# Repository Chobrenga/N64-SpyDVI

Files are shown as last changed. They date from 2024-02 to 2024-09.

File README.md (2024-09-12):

# Meet the N64 SpyDVI

N64 DVI mod board using RP2040 and some DVI bit banging firmware from the [PicoDVI-N64](https://github.com/kbeckmann/PicoDVI-N64) project. Should be able to be installed as cut or no cut.

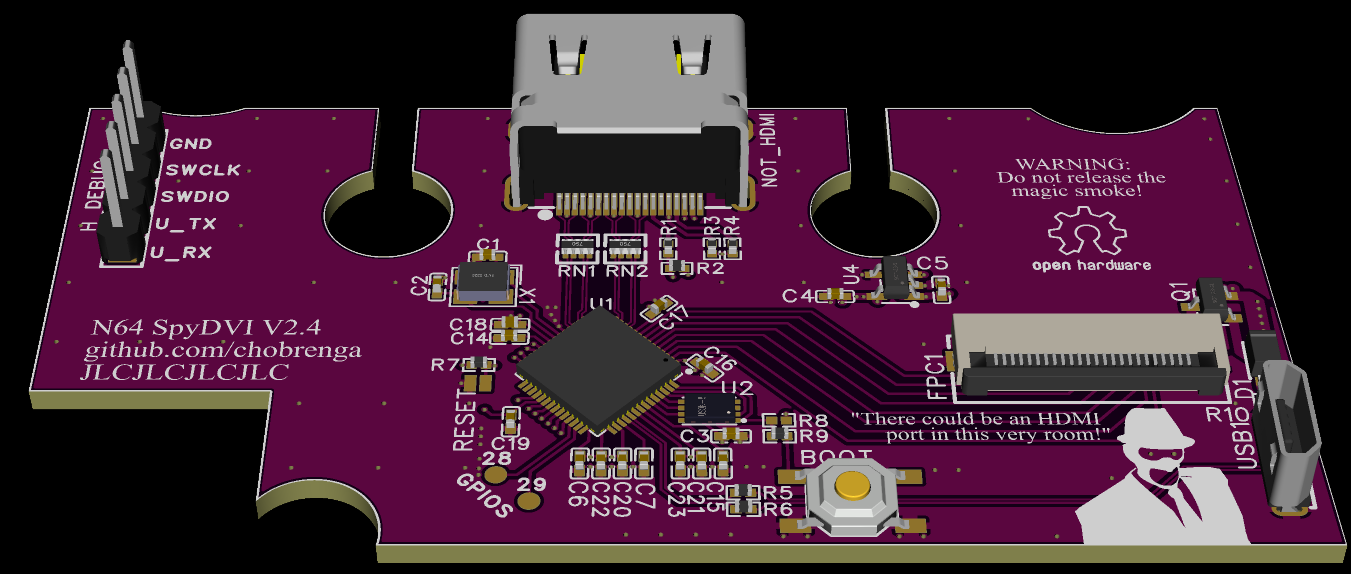
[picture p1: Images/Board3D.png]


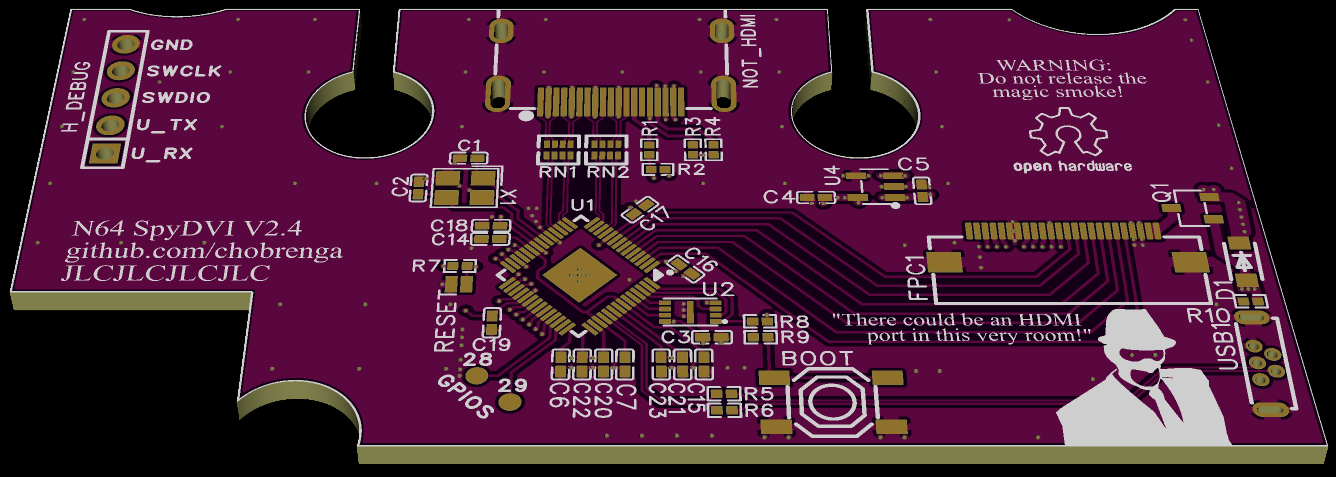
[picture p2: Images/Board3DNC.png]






~~Currently no QSB, use N64 Header. N64 Header is a 20 pin 1.27mm pitch connection, of which can be bought on Amazon.~~

Please use the QSB moving forward. The header had too many signaling issues. My first batch of the QSB is being ordered soon for testing. :)

The board only needs a 5V supply, there is a 3.3V regulator onboard to generate logic level. The RP2040 itself generates the 1.1V it needs for operaton. The MOSFET Q1 cuts off the 5V from the console when the usb is inserted, so it should be able to be programmed while installed.

Custom 3D printed bracket, braces, and facia are planned, but not yet available. The ones from Peter Bartmann's [n64adv2_pcb](https://github.com/borti4938/n64adv2_pcb) should work just fine.

# State of the Project

After receiving the flex cable and seeing the system working with audio finally, I began working on the software side of things. It very quickly became apparent to me that the 2040 is not a great choice for this kind of application, as the image distorts whenever I attempt to read controller inputs. This appears to be a performance issue. There may not be another update after this one.

# Fabrication Notes

~~This board has not been fabricated and tested as of yet. I have placed an order and will be testing very soon. If you do order, I always recommended the latest revision.~~

The board worked well enough that I will continue the project. With no audio lines connected, I got a clean video signal. Currently working on the QSB.

**R8** is intentionally missing on the BOM. It is not required. May be removed from schematic in final design.
**RESET** is missing in the BOM, this is because it's only a pair of pads. This is not an issue.

This is intended for fabrication with **JLC04161H-7628(Standard)**. Enable **impedance control**.

### Potential cost savings

Leaving the debug header unpopulated would save some cost for the final production run.

~~Removing the N64 pin header and stuffing resistors would reduce cost, once the QSB is available.~~

Potential to shrink the board layout and panelize the board, could significantly reduce manufacturing costs.

### Revision Notes

#### Main Board
* For V2.0 Select 0.15mm via option, 4-Wire Kelvin Test is mandatory. (Not recommended, use newer revision)
* For V2.1 Select 0.25mm via option, 4-Wire Kelvin Test is still mandatory.
* For V2.2 and beyond vias are 0.3mm minimum, so no special requirements regarding testing. This was done to reduce manufacturing costs.
* For V2.3 things were only slightly moved around. Was not worth going to the trouble to update the GitHub.
* For V2.4 the N64 Pin Header was removed along witht he stuffing resistors. Header was causing signal reflection issues.

#### Ribbon
* V1.0C is a compatibility version for main boards V2.0 and V2.1
* V1.0 is for V2.2 and newer. It has a few errors.
* V1.1 removes solder mask from the FPC connection area, along with fixing a few small issues.

This is not and will not be compatible with the Hispeedido flex cable, even though they have the same number of pins.

# Credit Given

Konrad Beckmann for initial inspiration and some initial firmware. Repo: [PicoDVI-N64](https://github.com/kbeckmann/PicoDVI-N64)

Wren6991 for sparking Konrad's project, and providing a functional DVI board schematic which my design is based on. [PicoDVI](https://github.com/Wren6991/PicoDVI)

The various and wonderful people in Konrad Beckmann's Discord server have also been a massive help! Thank you all!

# Schematics

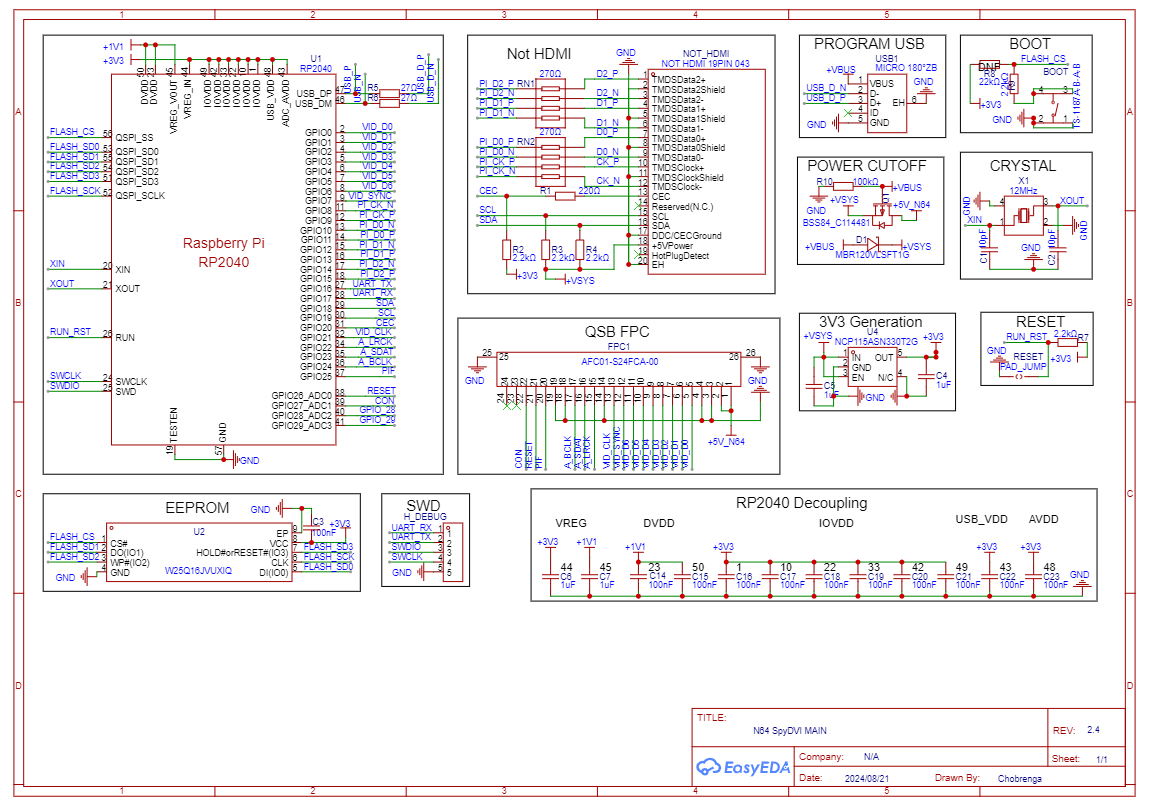
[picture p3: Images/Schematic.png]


## QSB Ribbon

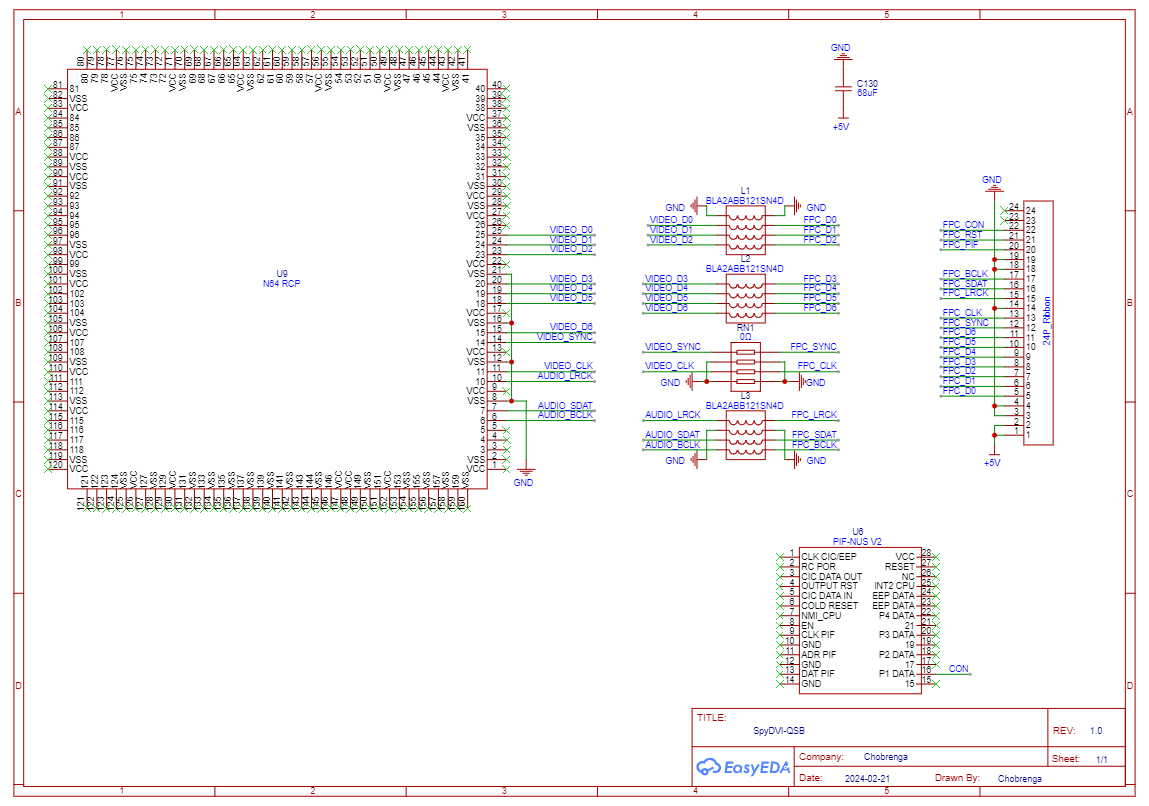
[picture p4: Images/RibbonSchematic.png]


# Wiring

Note: Controller support currently not implemented.
Note: The QSB handles all AV Signals. Power, GND, and CON still need wires.

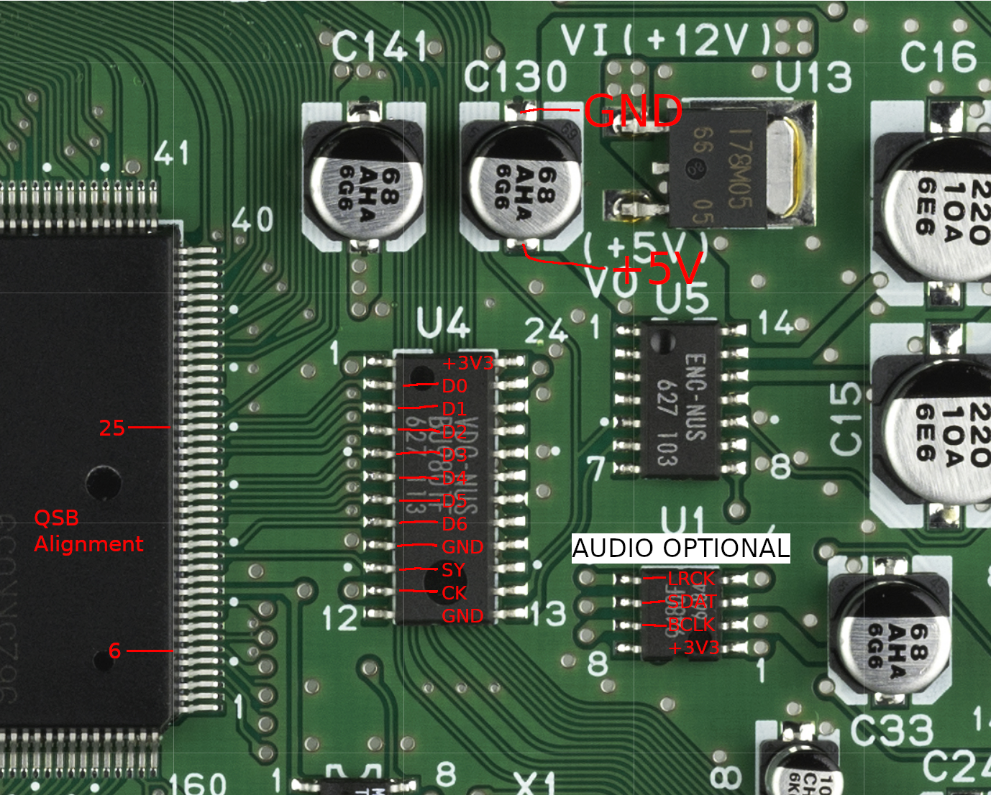
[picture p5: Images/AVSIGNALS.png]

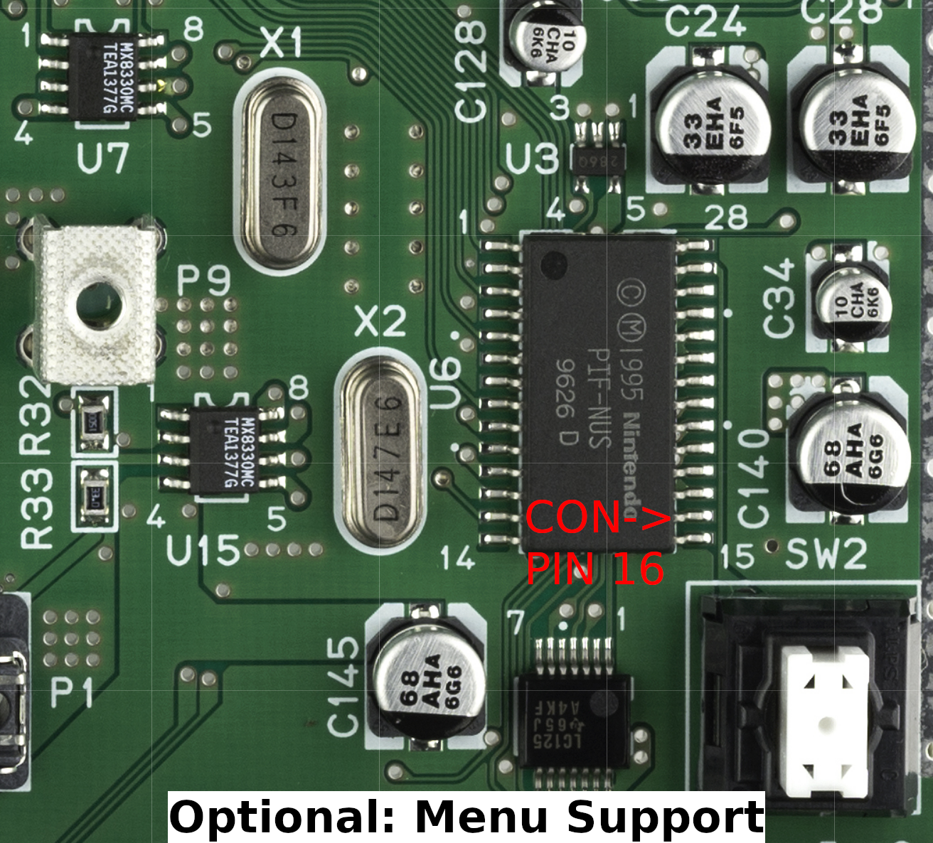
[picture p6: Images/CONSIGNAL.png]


Below is an example of an installed kit.

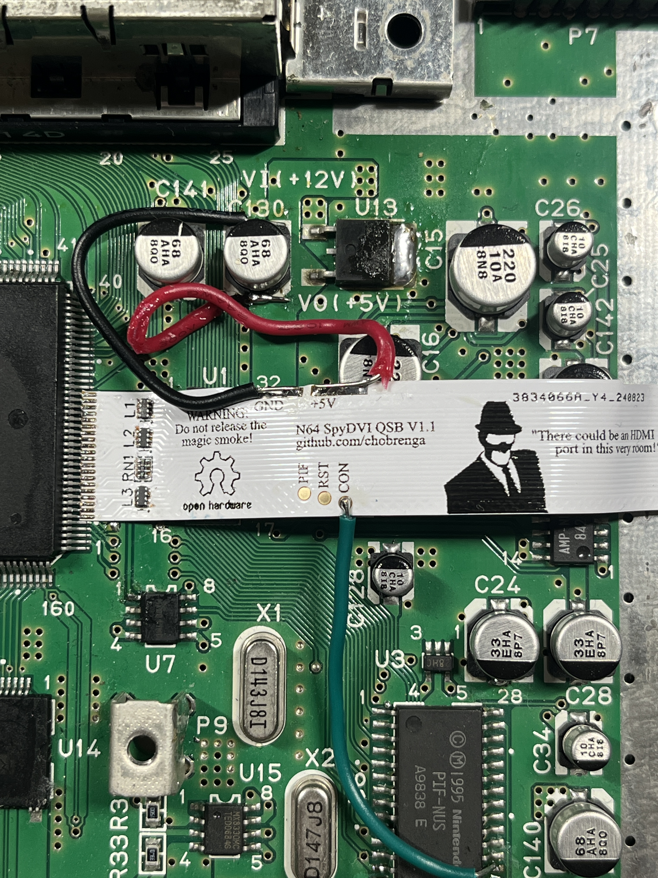
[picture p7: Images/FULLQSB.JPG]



# Board Layout

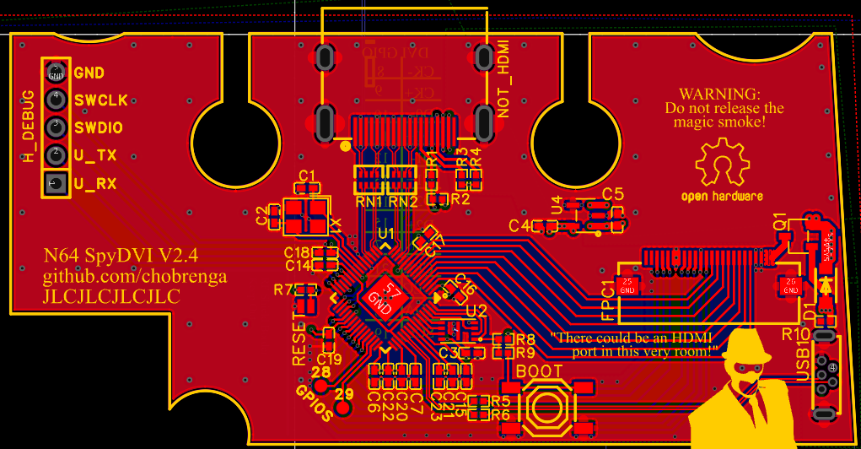
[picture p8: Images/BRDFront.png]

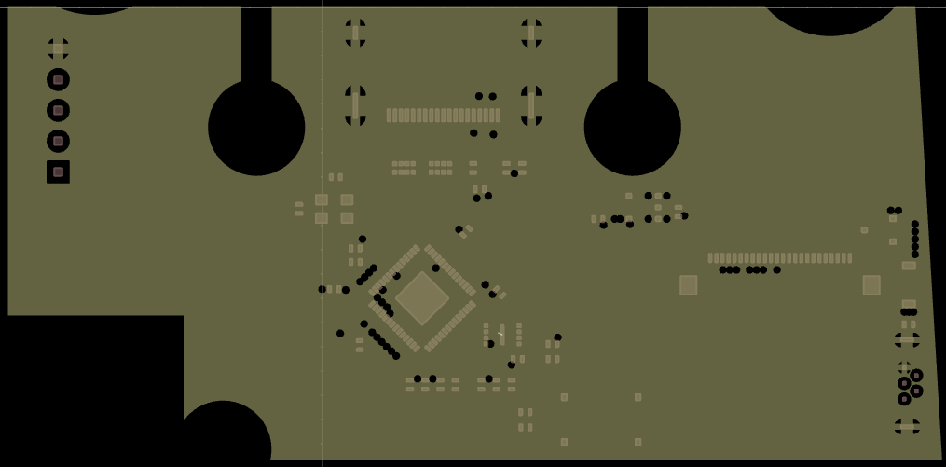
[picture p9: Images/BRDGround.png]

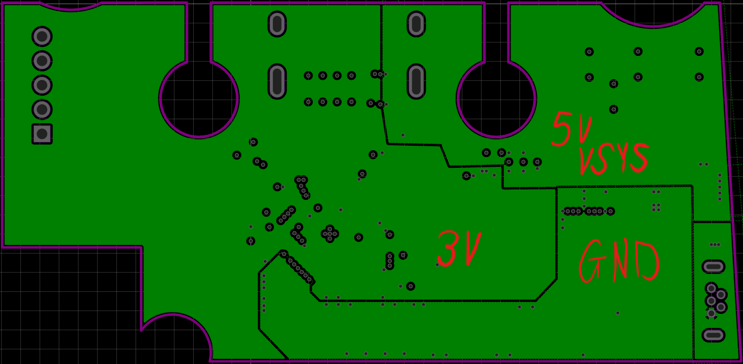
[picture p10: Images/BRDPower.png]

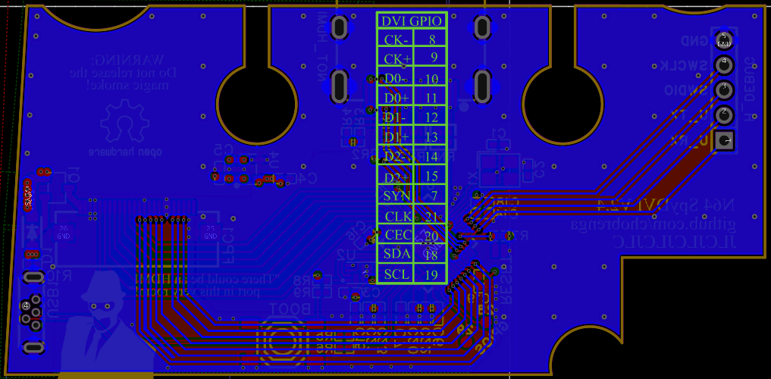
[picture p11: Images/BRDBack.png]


## Ribbon layout

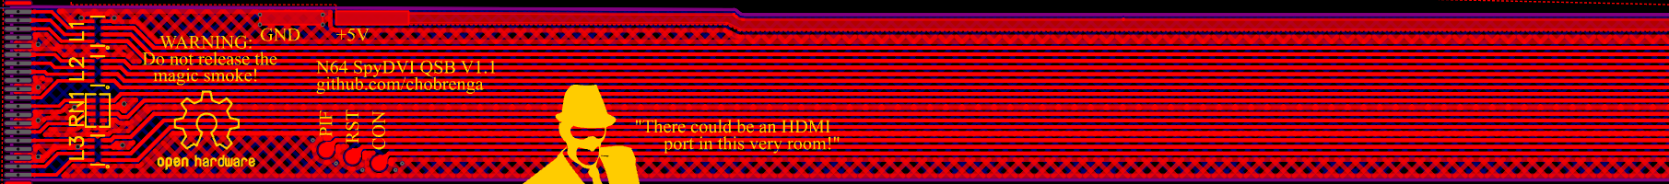
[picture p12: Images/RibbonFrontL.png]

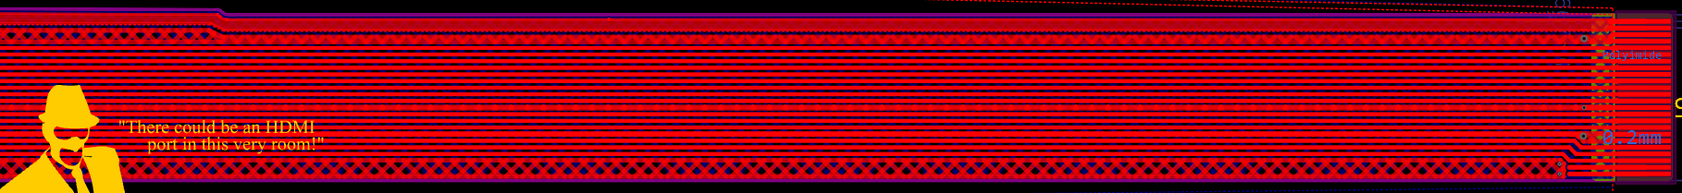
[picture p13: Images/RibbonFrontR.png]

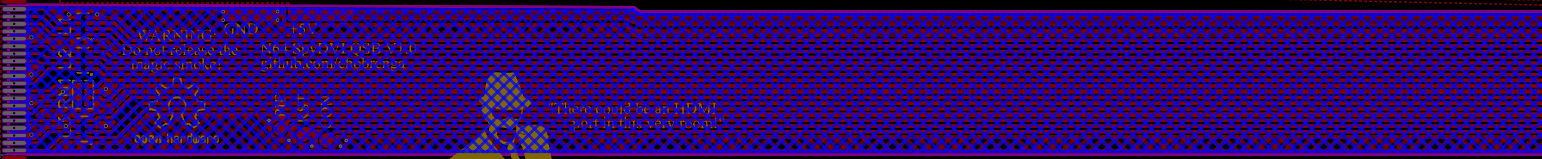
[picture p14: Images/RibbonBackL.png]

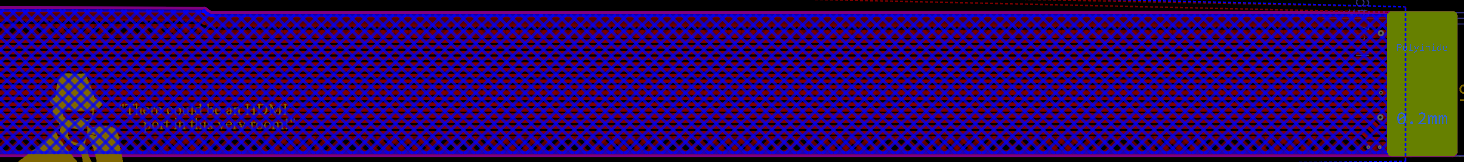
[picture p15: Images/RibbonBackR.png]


# Fitment

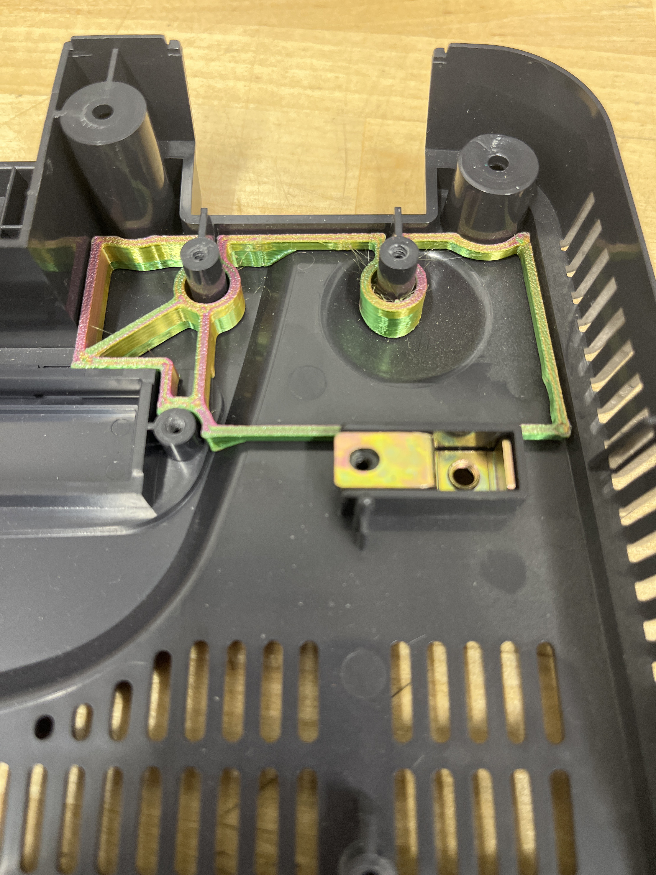
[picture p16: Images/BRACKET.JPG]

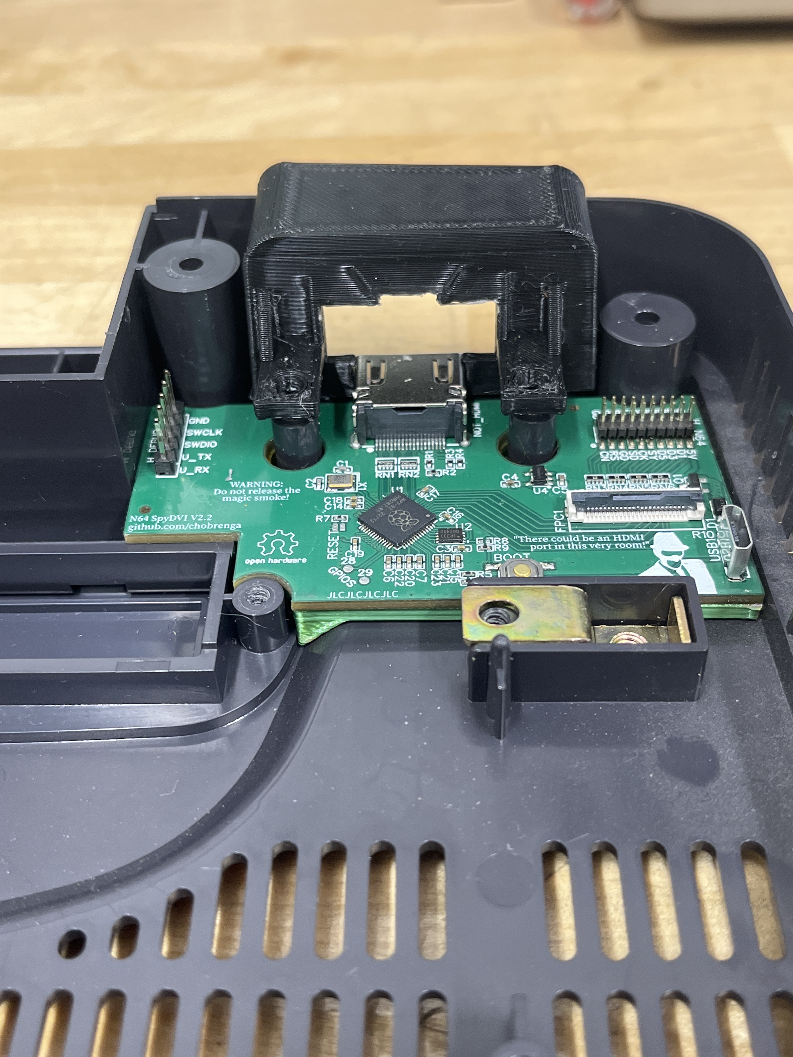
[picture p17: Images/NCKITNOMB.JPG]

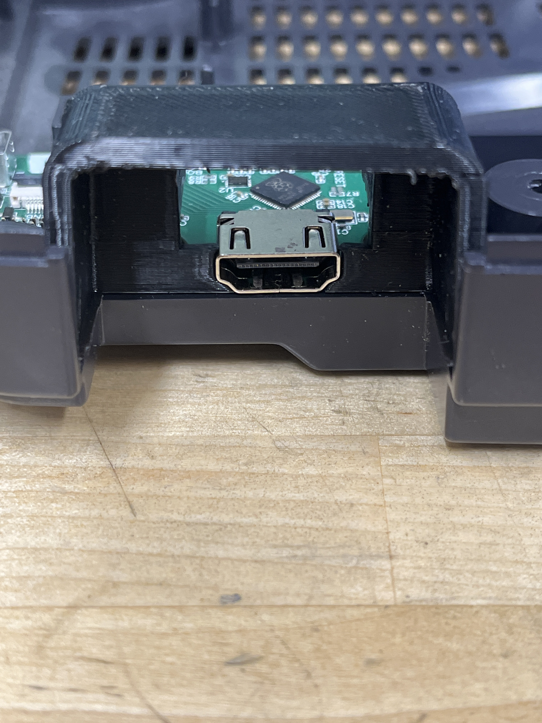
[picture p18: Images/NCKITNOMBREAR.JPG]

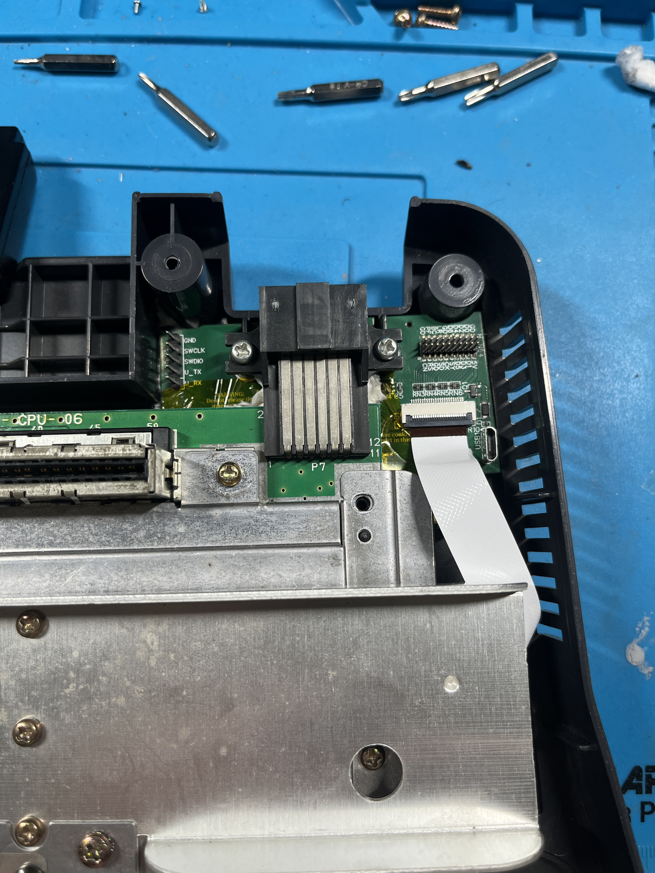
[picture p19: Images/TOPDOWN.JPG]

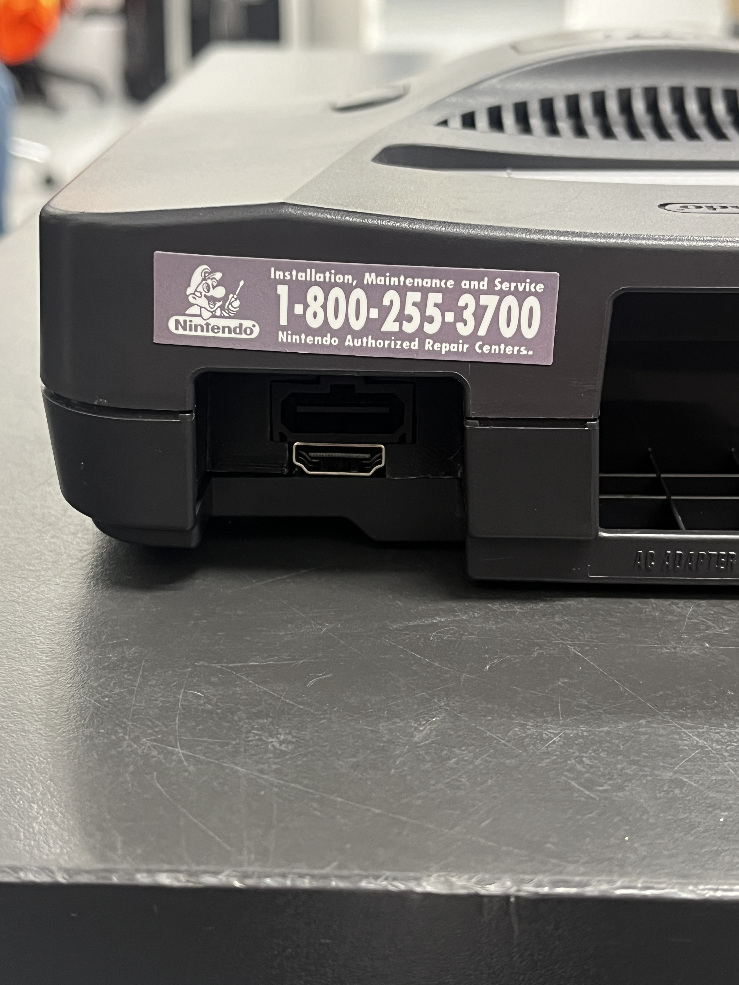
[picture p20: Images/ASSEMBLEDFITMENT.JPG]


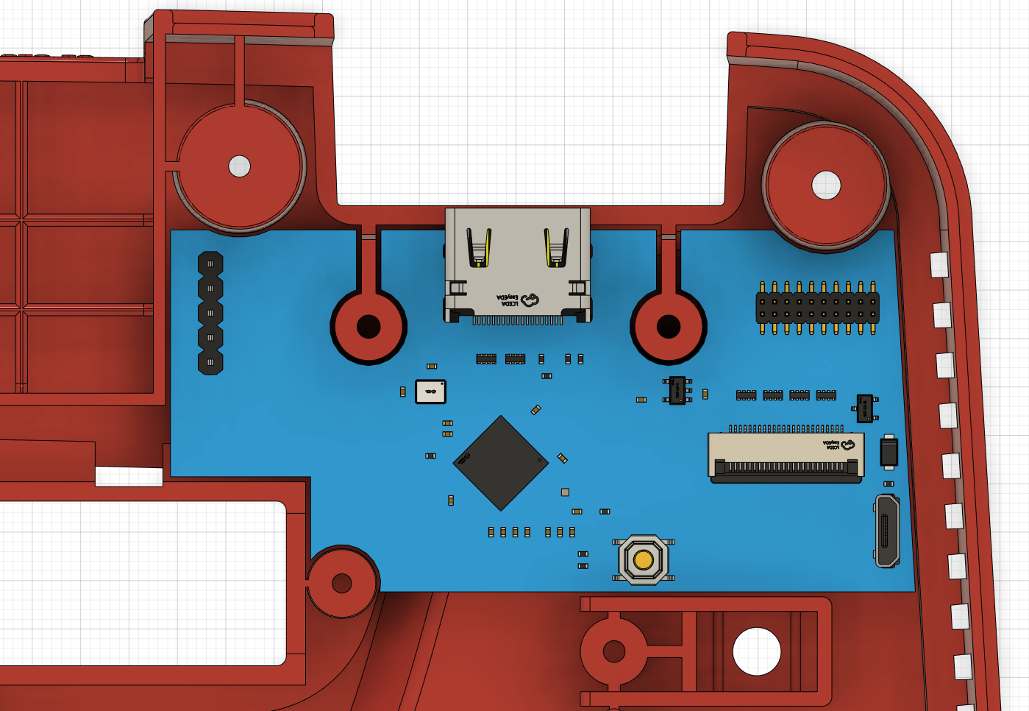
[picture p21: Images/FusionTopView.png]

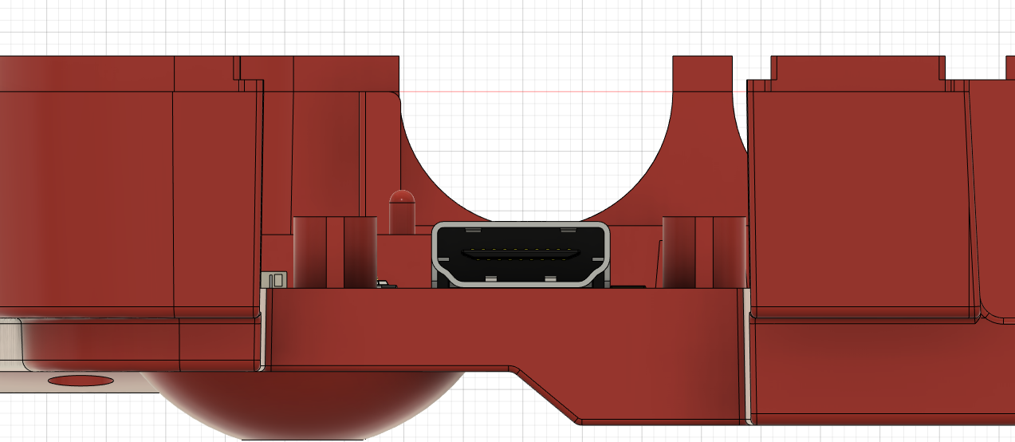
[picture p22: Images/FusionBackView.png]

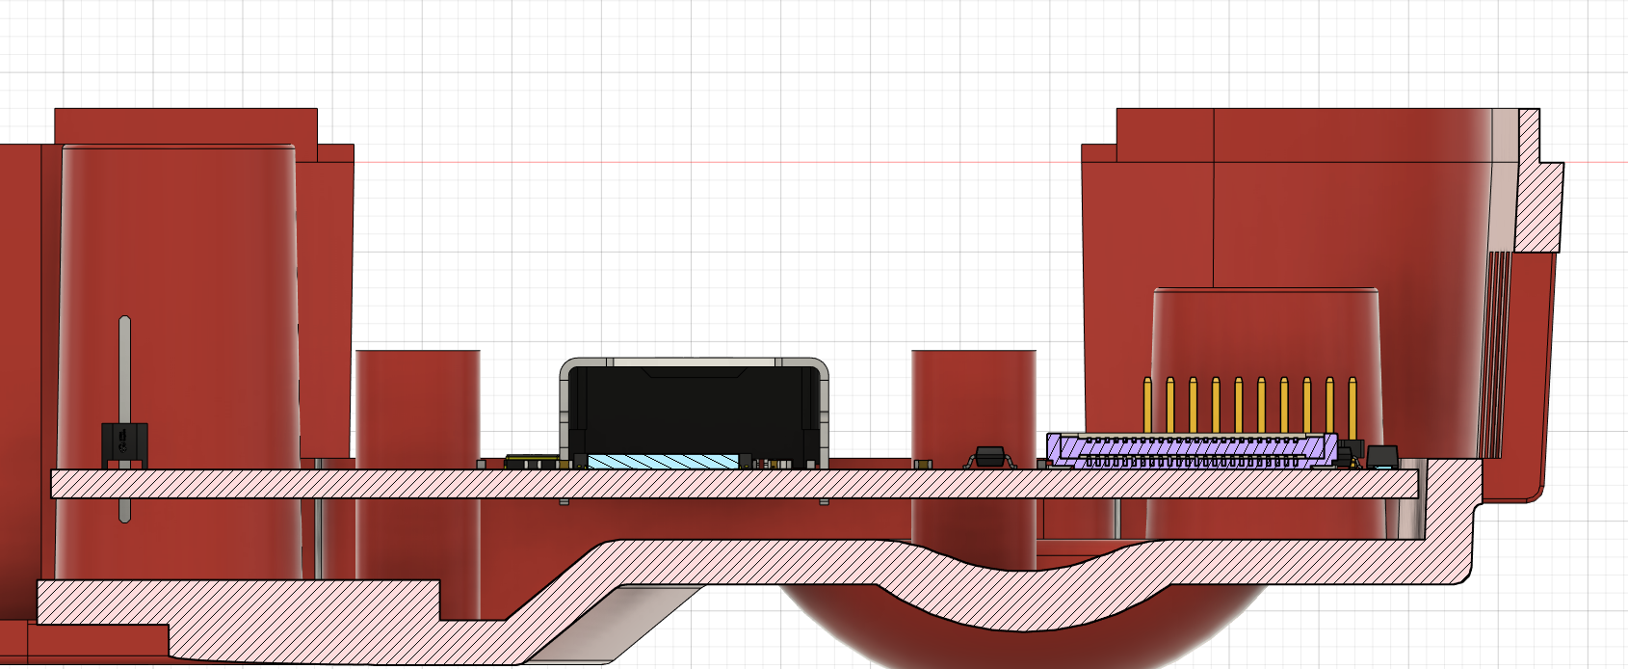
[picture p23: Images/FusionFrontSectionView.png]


# Software Notes

The project started with EasyEDA Standard edition, but has migrated to EasyEDA Pro for the Flex Cable support.

# Development Tasks
- [X] Layout Board
- [X] Order first production run
- [X] Modify Konrad's Firmware for SpyDVI
- [X] Test first production run
- [X] Add control monitoring
- [X] Design QSB Ribbon V1
- [X] Order QSB Ribbon V1
- [X] Take pictures of QSB install for Readme
- [X] ~Test QSB with an without V2.2 stuffing resistors~ No need, works with them.
- [X] Design Compatibility version of QSB Ribbon for older boards
- [X] Design 3D Printed No-Cut Kit
- [ ] Convert project to RP2350
- [ ] Find appropriate scaling methods
- [ ] Side-By-Side Test VS Multi Out
- [ ] Add settings menu and Hotkeys
- [ ] Design and order QSB with no components to see if they are necesarry.
- [ ] Design 3D Printed Cut Kit

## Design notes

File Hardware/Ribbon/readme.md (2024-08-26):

# Revisions
* V1.0C is a compatibility version for main boards V2.0 and V2.1
* V1.0 is for V2.2 and newer. It has a few errors.
* V1.1 removes solder mask from the FPC connection area, along with fixing a few small issues.

# Component Specs
* 3x 600mΩ ±25% 120Ω@100MHz Ferrite Beads (4 circuits)
* 1x 0Ω Resistor Array (4 circuits)

# BOM
* 3x BLA2ABB121SN4D L1, L2, L3
* 1x RC-MT08W000JT RN1

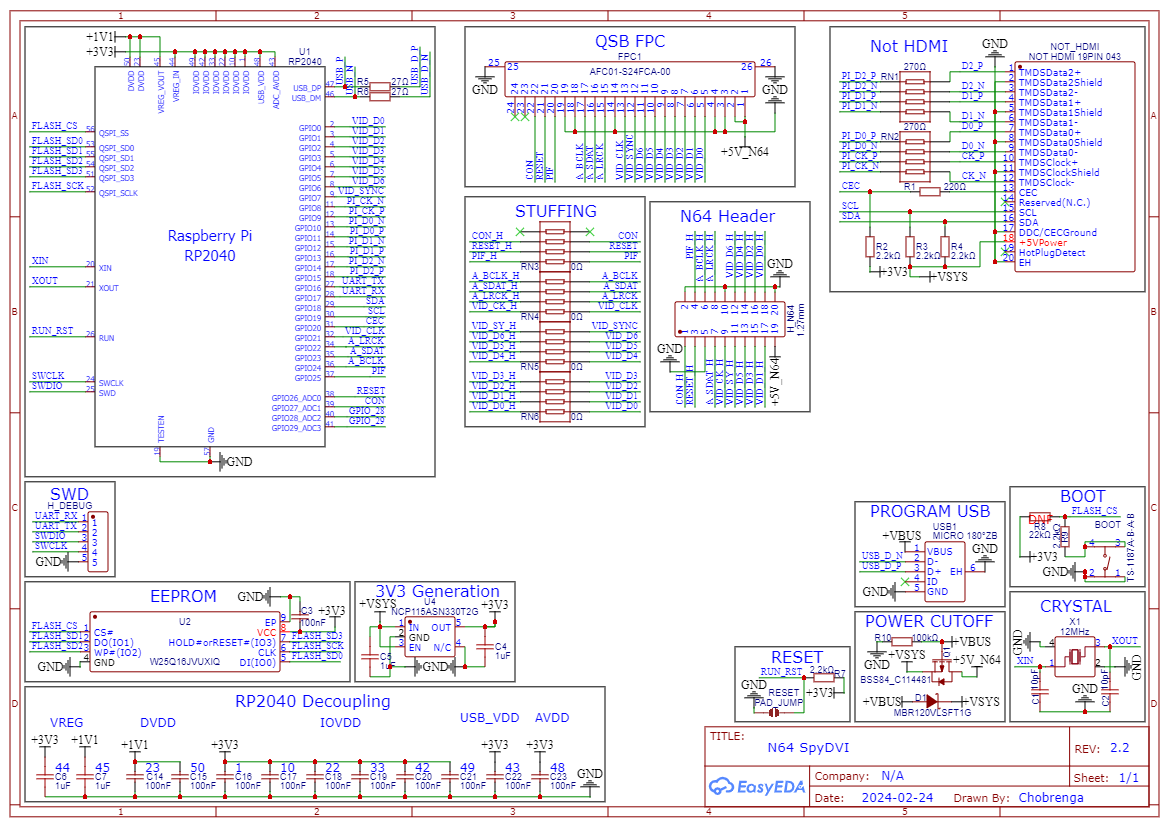
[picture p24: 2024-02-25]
Images/V2_2/Schematic.png

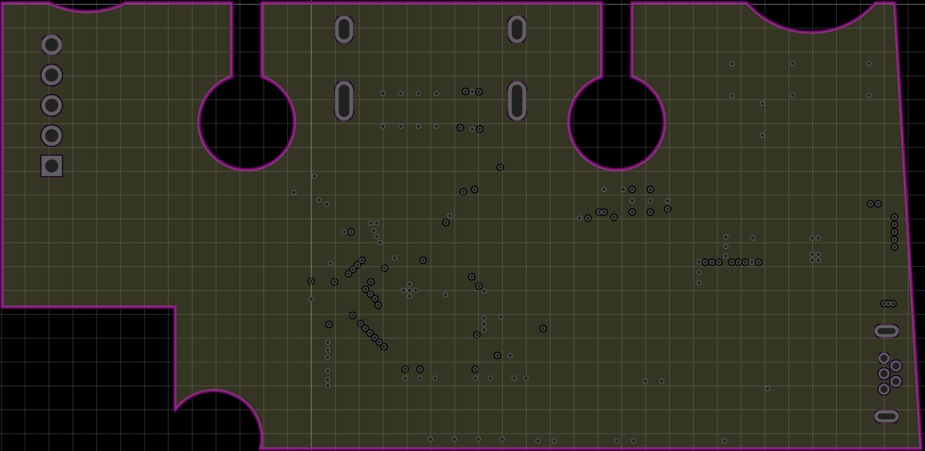
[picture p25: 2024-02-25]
Images/V2_2/BRDGround.png

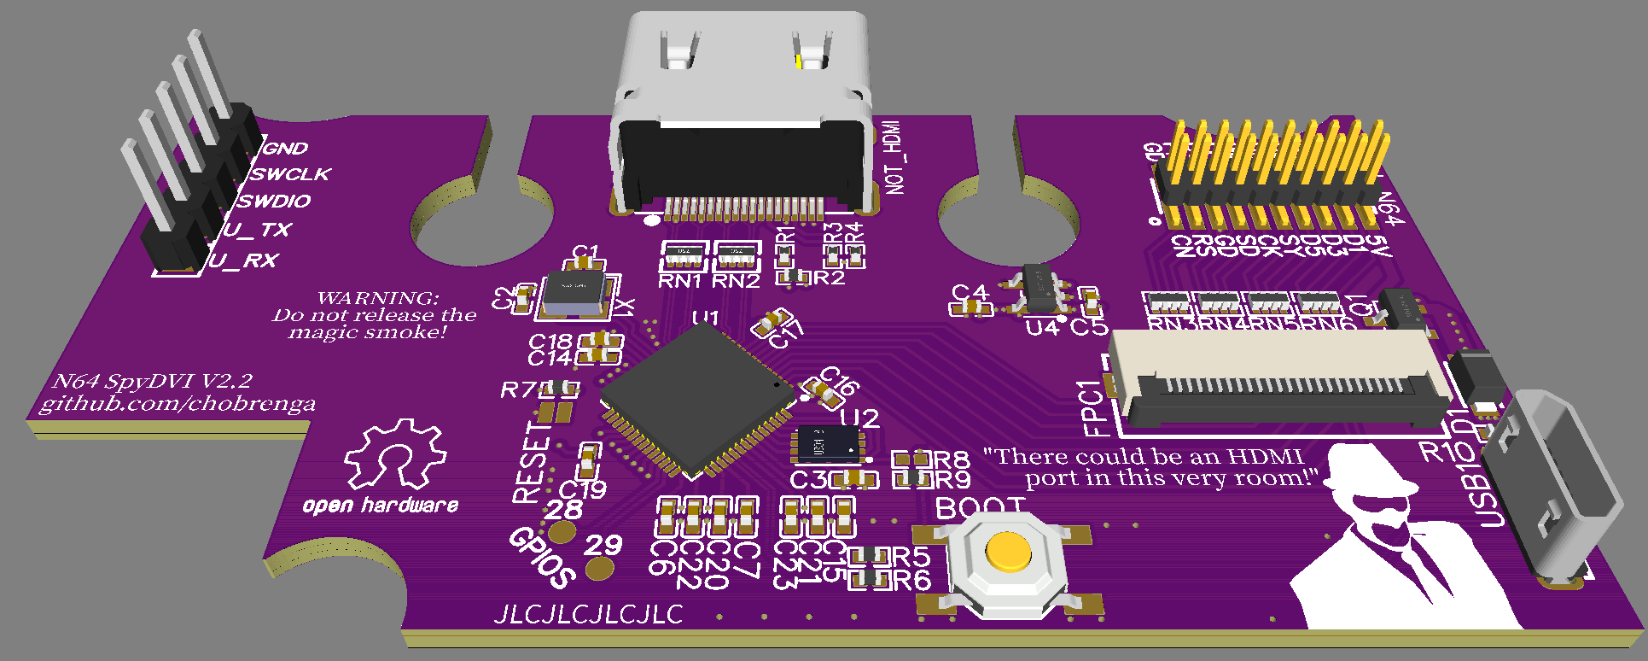
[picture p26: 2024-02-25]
Images/V2_2/Board3D.png

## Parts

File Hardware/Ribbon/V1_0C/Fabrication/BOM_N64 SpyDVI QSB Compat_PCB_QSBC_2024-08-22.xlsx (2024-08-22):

No. | Quantity | Comment | Designator | Footprint | Value | Manufacturer Part | Manufacturer | Supplier Part | Supplier
1 | 3 | BLA2ABB121SN4D | L1,L2,L3 | BEAD-SMD_8P-L2.0-W1.0-P0.50-TL |  | BLA2ABB121SN4D | muRata(村田) | C440126 | LCSC
2 | 1 | 0Ω | RN1 | RES-ARRAY-SMD_0402-8P-L2.0-W1.0-BL |  | RC-MT08W000JT | FH(风华) | C2001 | LCSC

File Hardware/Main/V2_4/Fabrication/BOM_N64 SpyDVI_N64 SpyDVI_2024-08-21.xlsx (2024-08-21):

No. | Quantity | Comment | Designator | Footprint | Value | Manufacturer Part | Manufacturer | Supplier Part | Supplier
1 | 1 | TS-1187A-B-A-B | BOOT | SW-SMD_4P-L5.1-W5.1-P3.70-LS6.5-TL-2 |  | TS-1187A-B-A-B | XKB Connectivity(中国星坤) | C318884 | LCSC
2 | 2 | 10pF | C1,C2 | C0402 |  | CL05C100JB5NNNC | SAMSUNG(三星) | C32949 | LCSC
3 | 11 | 100nF | C3,C14,C15,C16,C17,C18,C19,C20,C21,C22,C23 | C0402 |  | CL05B104KO5NNNC | SAMSUNG(三星) | C1525 | LCSC
4 | 4 | 1uF | C4,C5,C6,C7 | C0402 |  | CL05A105KA5NQNC | SAMSUNG(三星) | C52923 | LCSC
5 | 1 | MBR120VLSFT1G | D1 | SOD-123F_L2.8-W1.8-LS3.7-RD |  | MBR120VLSFT1G | onsemi(安森美) | C223608 | LCSC
6 | 1 | AFC01-S24FCA-00 | FPC1 | FPC-SMD_P0.50-24P_FGS-XJ-H2.0 |  | AFC01-S24FCA-00 | JS(钜硕电子) | C262669 | LCSC
7 | 1 | PZ254V-11-05P | H_DEBUG | HDR-TH_5P-P2.54-V-M |  | PZ254V-11-05P | XFCN(兴飞) | C492404 | LCSC
8 | 1 | NOT HDMI 19PIN 043 | NOT_HDMI | HDMI-SMD_HDMI-19PIN-043 |  | HDMI 19PIN 043 | SHOU HAN(首韩) | C2858275 | LCSC
9 | 1 | BSS84_C114481 | Q1 | SOT-23-3_L2.9-W1.6-P1.90-LS2.8-BR |  | BSS84 | CJ(江苏长电/长晶) | C114481 | LCSC
10 | 1 | 220Ω | R1 | R0402 |  | 0402WGF2200TCE | UNI-ROYAL(厚声) | C25091 | LCSC
11 | 5 | 2.2kΩ | R2,R3,R4,R7,R9 | R0402 |  | 0402WGF2201TCE | UNI-ROYAL(厚声) | C25879 | LCSC
12 | 2 | 27Ω | R5,R6 | R0402 |  | 0402WGF270JTCE | UNI-ROYAL(厚声) | C25100 | LCSC
13 | 1 | 22kΩ | R8 | R0402
14 | 1 | 100kΩ | R10 | R0402 |  | 0402WGF1003TCE | UNI-ROYAL(厚声) | C25741 | LCSC
15 | 1 | PAD_JUMP | RESET | PAD-JUMPER-2-NO_NO_SILK
16 | 2 | 270Ω | RN1,RN2 | RES-ARRAY-SMD_0804-8P-L2.0-W1.0-BL |  | CAT10-271J4LF | BOURNS | C148510 | LCSC
17 | 1 | RP2040 | U1 | LQFN-56_L7.0-W7.0-P0.4-EP |  | RP2040 | Raspberry Pi(树莓派) | C2040 | LCSC
18 | 1 | W25Q16JVUXIQ | U2 | USON-8_L3.0-W2.0-P0.50-BL-EP |  | W25Q16JVUXIQ | WINBOND(华邦) | C2843335 | LCSC
19 | 1 | NCP115ASN330T2G | U4 | SOT-23-5_L3.0-W1.7-P0.95-LS2.8-BL |  | NCP115ASN330T2G | onsemi(安森美) | C603505 | LCSC
20 | 1 | MICRO 180°ZB | USB1 | MICRO-USB-TH_MICRO-180-ZB |  | MICRO 180°ZB | SHOU HAN(首韩) | C668588 | LCSC
21 | 1 | 12MHz | X1 | CRYSTAL-SMD_4P-L3.2-W2.5-BL |  | X322512MMB4SI | YXC(扬兴晶振) | C50430 | LCSC

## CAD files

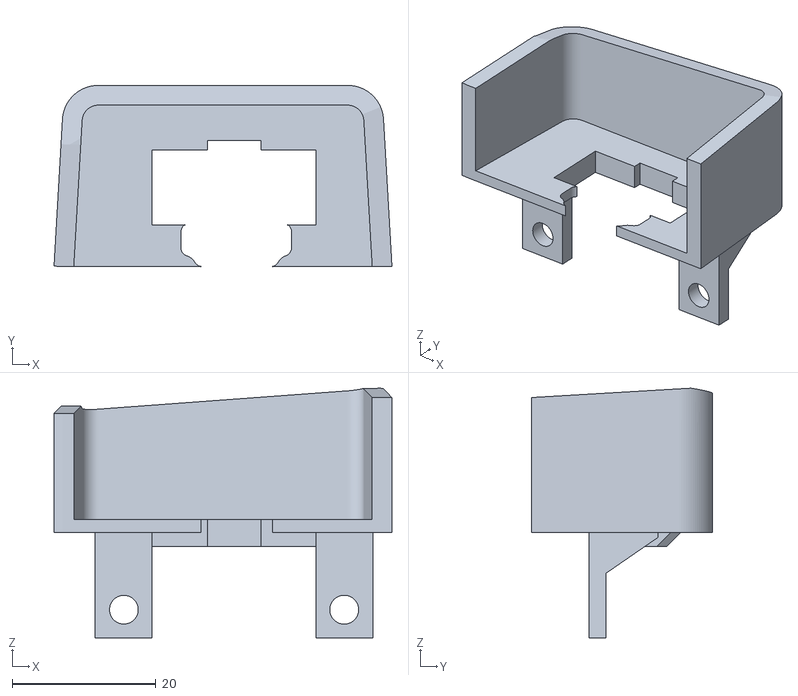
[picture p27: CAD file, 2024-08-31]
3D Files/N64Adv2_MultiOut_NoCut.stl
47.1 x 25.3 x 34.8

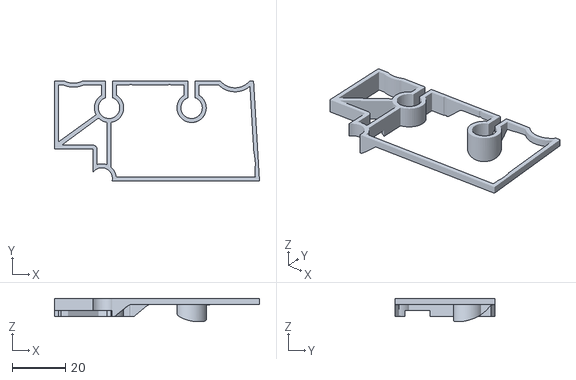
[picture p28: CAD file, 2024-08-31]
3D Files/N64 Bracket.stl
77.0 x 37.4 x 8.79

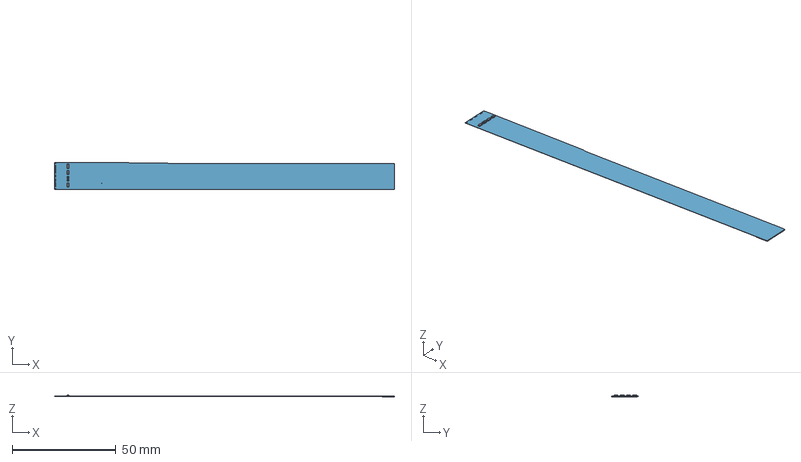
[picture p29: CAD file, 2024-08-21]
3D Files/N64 SpyDVI QSB_1_0.step
163.9 x 13.1 x 0.753 mm
Board

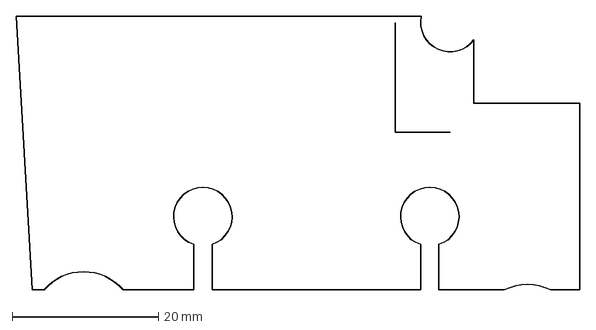
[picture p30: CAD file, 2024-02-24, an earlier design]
Hardware/Main/V2_0/SpyDVIBoardOutline.dxf
77.0 x 37.4 mm

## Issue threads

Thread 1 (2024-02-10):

R8 missing in BOM

bbsan2k, 2024-02-10:
Hi,
Thanks for this great project!
Is it possible, that R8 is missing in the BOM file?

Chobrenga, 2024-02-11:
That was intentional. It is there so there are pads to add a 22k pull-up if there are issues with the FLASH_CS/BOOT signal. The RP2040 has an internal 60k 20% pull-up on that line.

If you're planning to produce the board as it sits, I must warn you I've been made aware of several design oversights and it may not work at all. I'm fed up with EasyEDA crashing also, and am currently porting the project to Kicad.

bbsan2k, 2024-02-11:
Thanks for your reply! That’s really good to know - I guess I’ll wait for the new version then😉
I was looking for exactly this kind of board😊

Closed 2024-02-11.

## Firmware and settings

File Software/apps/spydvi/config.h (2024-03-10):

/**
 * SPDX-License-Identifier: BSD-3-Clause
 *
 * Copyright (c) 2023 Konrad Beckmann
 */

/**
 * @file config.h
 * @brief Configuration management functions and global configuration variable.
 */

#pragma once

#include <stdint.h>

/// Default crop X parameter for PAL.
#define DEFAULT_CROP_X_PAL  (36)

/// Default crop X parameter for NTSC.
#define DEFAULT_CROP_X_NTSC (14)

/// Default crop Y parameter for PAL.
#define DEFAULT_CROP_Y_PAL  (90)

/// Default crop Y parameter for NTSC.
#define DEFAULT_CROP_Y_NTSC (25)

/// Number of rows for PAL.
#define ROWS_PAL            (615)

/// Number of rows for NTSC.
#define ROWS_NTSC           (511)

/// Tolerance for number of rows.
#define ROWS_TOLERANCE      (5)

/// Y offset for OSD.
#define OSD_Y_OFFSET (3)

/// X offset for OSD.
#define OSD_X_OFFSET (5)

/// TMDS bit clock 252 MHz
/// DVDD 1.2V (1.1V seems ok too)
/// Voltage regulator selection.
#define VREG_VSEL VREG_VOLTAGE_1_20

/// DVI timing configuration.
#define DVI_TIMING dvi_timing_640x480p_60hz

/// UART config on the last GPIOs
/// UART transmission pin.
#define UART_TX_PIN (16)

/// UART reception pin (not available on the pico).
#define UART_RX_PIN (17)

/// UART identifier.
#define UART_ID     uart0

/// Baud rate for UART communication.
#define BAUD_RATE   115200

/**
 * @brief The number of bits to shift to get the audio buffer size.
 *
 * This value is used to calculate the size of the audio buffer by shifting
 * 1 to the left by this number of bits. For example, if
 * AUDIO_BUFFER_SIZE_BITS is 12, then the audio buffer size will be
 * 1 << 12, or 4096.
 */
#define AUDIO_BUFFER_SIZE_BITS 12

/**
 * @brief The size of the audio buffer.
 *
 * This is calculated as 1 << AUDIO_BUFFER_SIZE_BITS. So if
 * AUDIO_BUFFER_SIZE_BITS is 12, then AUDIO_BUFFER_SIZE will be 4096.
 */
#define AUDIO_BUFFER_SIZE (1 << AUDIO_BUFFER_SIZE_BITS)

/**
 * @def USE_RGB555
 * @brief A macro to control the color depth of the display.
 *
 * When defined, the display will use RGB555 color depth, which provides
 * 5 bits for each of the red, green, and blue color channels. This results
 * in a total of 32,768 possible colors.
 *
 * RGB555 can sometimes look better than RGB565 because it provides a balanced
 * color depth across all three color channels. This can result in more accurate
 * color reproduction, especially for images that have a balanced mix of colors.
 * However, it does provide fewer total colors than RGB565.
 *
 * If this macro is not defined, and USE_RGB565 is defined instead, the display
 * will use RGB565 color depth. This provides 5 bits for red, 6 bits for green,
 * and 5 bits for blue, resulting in a total of 65,536 possible colors. The
 * extra bit for the green channel is because the human eye is more sensitive
 * to variations in green than in red or blue.
 */
#define USE_RGB555
// #define USE_RGB565

/**
 * @def AUDIO_ENABLED
 * @brief A macro to control the audio input functionality.
 *
 * When set to 1, the audio input functionality is enabled. This means that the
 * application will process and output audio data. However, this will only work
 * if the necessary audio input wires have been correctly soldered to the
 * appropriate pins on the hardware.
 *
 * When set to 0, the audio input functionality is disabled. This can be useful
 * for debugging, or when running on hardware where the audio input wires have
 * not been soldered.
 */
#define AUDIO_ENABLED 1
// #define AUDIO_ENABLED 0

/**
 * @def DIAGNOSTICS
 * @brief A macro to control the display of diagnostic data.
 *
 * When defined, the application will print diagnostic data on the screen.
 * This can be useful for debugging and performance tuning.
 *
 * When not defined, no diagnostic data will be displayed.
 */
// #define DIAGNOSTICS

/**
 * @def DIAGNOSTICS_JOYBUS
 * @brief A macro to control the display of Joybus diagnostic data.
 *
 * When defined, the application will print Joybus-specific diagnostic data
 * on the screen. This can be useful for debugging and performance tuning
 * of the Joybus communication.
 *
 * When not defined, no Joybus diagnostic data will be displayed.
 */
// #define DIAGNOSTICS_JOYBUS

/**
 * @def CONFIG_MAGIC1
 * @brief A magic number used for configuration validation.
 *
 * This magic number is used as part of a mechanism to validate the
 * configuration data. It should be stored in a known location in the
 * configuration data, and checked when the configuration data is read.
 * If it does not match the expected value, this indicates that the
 * configuration data is not valid, and default values should be used instead.
 */
#define CONFIG_MAGIC1 0x12345678

/**
 * @def CONFIG_MAGIC2
 * @brief A second magic number used for configuration validation.
 *
 * This magic number is used as part of a mechanism to validate the
 * configuration data, in conjunction with CONFIG_MAGIC1. It provides an
 * additional check to ensure the integrity of the configuration data.
 */
#define CONFIG_MAGIC2 0xdeadf00d

/**
 * @enum dvi_color_mode
 * @brief Enumerates the supported color modes.
 */
typedef enum dvi_color_mode {
    DVI_RGB_555 = 0, ///< 15-bit color mode (5 bits each for red, green, and blue).
    DVI_RGB_565,     ///< 16-bit color mode (5 bits for red and blue, 6 bits for green).
    DVI_RGB_888,     ///< 24-bit color mode (8 bits each for red, green, and blue).
} dvi_color_mode_t;

/**
 * @enum sample_rate_hz
 * @brief Enumerates the supported output audio sample rates in Hertz.
 */
typedef enum sample_rate_hz {
    SAMPLE_RATE_32000_HZ = 32000, ///< 32,000 Hz sample rate.
    SAMPLE_RATE_44100_HZ = 44100, ///< 44,100 Hz sample rate.
    SAMPLE_RATE_48000_HZ = 48000, ///< 48,000 Hz sample rate.
    SAMPLE_RATE_96000_HZ = 96000, ///< 96,000 Hz sample rate.
} sample_rate_hz_t;

/**
 * @struct config
 * @brief Represents the configuration for the application.
 */
typedef struct config {
    uint32_t magic1;                ///< The first magic number used for configuration validation.
    uint32_t audio_out_sample_rate; ///< The audio output sample rate in Hertz (see @ref sample_rate_hz_t).
    uint32_t dvi_color_mode;        ///< The DVI color mode (see @ref dvi_color_mode_t).
    uint32_t magic2;                ///< The second magic number used for configuration validation.
} config_t;

/**
 * @brief Global configuration variable.
 *
 * This variable holds the current configuration for the application.
 * It can be initialized with default values using config_init(),
 * loaded from flash memory using config_load(), and saved to flash
 * memory using config_save().
 */
extern config_t g_config;

/**
 * @brief Initializes the global configuration with default values.
 *
 * This function sets the fields of g_config to their default values.
 * It should be called when the application starts, before any other
 * configuration management functions are used.
 */
void config_init(void);

/**
 * @brief Loads the configuration from flash memory into g_config.
 *
 * This function reads the configuration data from flash memory and
 * stores it in g_config. If the configuration data in flash memory
 * is not valid (as determined by the magic numbers), this function
 * will leave g_config unchanged.
 */
void config_load(void);

/**
 * @brief Saves the configuration from g_config to flash memory.
 *
 * This function writes the configuration data from g_config to flash
 * memory. This allows the current configuration to be preserved when
 * the application is restarted.
 */
void config_save(void);

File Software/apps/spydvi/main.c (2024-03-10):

/**
 * SPDX-License-Identifier: BSD-3-Clause
 *
 * Copyright (c) 2023 Konrad Beckmann
 */

// #pragma GCC optimize("Os")
// #pragma GCC optimize("O2")
#pragma GCC optimize("O3")


#include "config.h"

#include <stdio.h>
#include <stdlib.h>
#include <stdarg.h>
#include "hardware/vreg.h"
#include "pico/multicore.h"
#include "pico/stdlib.h"
#include "hardware/dma.h"
#include "hardware/uart.h"

#include "dvi.h"
#include "dvi_serialiser.h"
#include "common_dvi_pin_configs.h"
#include "sprite.h"

#include "joybus.h"

#include "joybus.pio.h"
#include "n64.pio.h" // n64.pio contains pin mapping :)

#include "gfx.h"
#include "osd.h"

// Enable to print debug/diagnostics
//#define DIAGNOSTICS
//#define DIAGNOSTICS_JOYBUS

// Crop configuration for PAL vs NTSC
#define IN_RANGE(__x, __low, __high) (((__x) >= (__low)) && ((__x) <= (__high)))
#define IN_TOLERANCE(__x, __value, __tolerance) IN_RANGE(__x, (__value - __tolerance), (__value + __tolerance))

#define ARRAY_SIZE(x) (sizeof(x)/sizeof(x[0]))

const PIO pio_joybus = DVI_DEFAULT_SERIAL_CONFIG.pio; // usually pio0
const uint sm_joybus = 3; // last free sm in pio0 unless sm_tmds is set to something unusual

const PIO pio = (DVI_DEFAULT_SERIAL_CONFIG.pio == pio0) ? pio1 : pio0;
const uint sm_video = 0;
const uint sm_audio = 1;
struct dvi_inst dvi0;

// __no_inline_not_in_flash_func
// __time_critical_func
// __not_in_flash_func

audio_sample_t      last_audio_sample;
audio_sample_t      audio_buffer[AUDIO_BUFFER_SIZE];

static void core1_main(void)
{
    dvi_register_irqs_this_core(&dvi0, DMA_IRQ_0);
    dvi_start(&dvi0);
    dvi_scanbuf_main_16bpp(&dvi0);
    __builtin_unreachable();
}

static void core1_scanline_callback(uint arg0)
{
    // Discard any scanline pointers passed back
    uint16_t *bufptr;
    while (queue_try_remove_u32(&dvi0.q_colour_free, &bufptr))
        ;
    // Note first two scanlines are pushed before DVI start
    static uint scanline = 2;
    bufptr = &g_framebuf[FRAME_WIDTH * scanline];
    queue_add_blocking_u32(&dvi0.q_colour_valid, &bufptr);
    scanline = (scanline + 1) % FRAME_HEIGHT;
}

static void set_audio_dvi_parameters(sample_rate_hz_t samplerate, bool setup)
{
	
    uint32_t cts;
    uint32_t n;

    switch (samplerate) {
    case SAMPLE_RATE_96000_HZ:
        cts = 25200;
        n = 6144 * 2;
        break;
    case SAMPLE_RATE_48000_HZ:
        cts = 25200;
        n = 6144;
        break;
    case SAMPLE_RATE_44100_HZ:
        cts = 28000;
        n = 6272;
        break;
    case SAMPLE_RATE_32000_HZ:
        cts = 25200;
        n = 4096;
        break;
    default:
        // Assume a freq. close to 32000, so let's use that
        cts = 25200;
        n = (128 * samplerate * cts) / 25200000;
        break;
    }

    if (setup) {
        dvi_set_audio_freq(&dvi0, samplerate, cts, n);
    } else {
        dvi_update_audio_freq(&dvi0, samplerate, cts, n);
    }
}

static void set_audio_sampling_parameters(sample_rate_hz_t samplerate)
{
    uint16_t numerator;
    uint16_t denominator;

    switch (samplerate) {
    case SAMPLE_RATE_96000_HZ:
        numerator = 1;
        denominator = 2625; // No error
        break;
    case SAMPLE_RATE_48000_HZ:
        numerator = 1;
        denominator = 5250; // No error
        break;
    case SAMPLE_RATE_44100_HZ:
        numerator = 4;
        denominator = 22857; // Actual freq. 44100.28 Hz
        break;
    case SAMPLE_RATE_32000_HZ:
        numerator = 1;
        denominator = 7875; // No error
        break;
    default:
        numerator = 1;
        denominator = 252000000 / samplerate; // There might be rounding errors
        break;
    }

    dma_timer_set_fraction(0, numerator, denominator);
}

void set_input_pin(int pin, bool pullup, bool pulldown)
{
	gpio_init(pin);
	gpio_set_dir(pin, GPIO_IN);

	// Enable weak internal pull downs to reduce noise when n64 is turned off
    gpio_set_pulls(pin, false, true);
}

int main(void)
{
	config_init();
    config_load();

    vreg_set_voltage(VREG_VSEL);
    sleep_ms(10);

    // Run system at TMDS bit clock (252.000 MHz)
    set_sys_clock_khz(DVI_TIMING.bit_clk_khz, true);

    // setup_default_uart();
    stdio_uart_init_full(UART_ID, BAUD_RATE, UART_TX_PIN, UART_RX_PIN);
	printf("\n");
	sleep_ms(10);
	printf("UART BEGIN\n");

    printf("Configuring DVI\n");

    gfx_init();
    dvi0.timing = &DVI_TIMING;
    dvi0.ser_cfg = DVI_DEFAULT_SERIAL_CONFIG;
    dvi0.scanline_callback = core1_scanline_callback;
    dvi_init(&dvi0, next_striped_spin_lock_num(), next_striped_spin_lock_num());

    // Once we've given core 1 the g_framebuffer, it will just keep on displaying
    // it without any intervention from core 0

#ifdef DIAGNOSTICS
	// Fill with red
    sprite_fill16(g_framebuf, RGB888_TO_RGB565(0xFF, 0x00, 0x00), FRAME_WIDTH * FRAME_HEIGHT);
#else
    // Fill with black
    sprite_fill16(g_framebuf, RGB888_TO_RGB565(0x00, 0x00, 0x00), FRAME_WIDTH * FRAME_HEIGHT);
#endif

    uint16_t *bufptr = g_framebuf;
    queue_add_blocking_u32(&dvi0.q_colour_valid, &bufptr);
    bufptr += FRAME_WIDTH;
    queue_add_blocking_u32(&dvi0.q_colour_valid, &bufptr);

     // HDMI Audio related
    dvi_get_blank_settings(&dvi0)->top    = 4 * 0;
    dvi_get_blank_settings(&dvi0)->bottom = 4 * 0;

    set_audio_dvi_parameters(g_config.audio_out_sample_rate, true);

    printf("Core 1 start\n");
    multicore_launch_core1(core1_main);

    printf("Start rendering\n");

/* Does not work on boards that skip any pins for the AV signals
    for (int i = PIN_VIDEO_D0; i <= PIN_AUDIO_BCLK; i++) {
        gpio_init(i);
        gpio_set_dir(i, GPIO_IN);

        // Enable weak internal pull downs to reduce noise when n64 is turned off
        gpio_set_pulls(i, false, true);
    }*/
	
	bool setAVPulldown = true;
	set_input_pin(n64_VIDEO_D0, false, setAVPulldown);
	set_input_pin(n64_VIDEO_D1, false, setAVPulldown);
	set_input_pin(n64_VIDEO_D2, false, setAVPulldown);
	set_input_pin(n64_VIDEO_D3, false, setAVPulldown);
	set_input_pin(n64_VIDEO_D4, false, setAVPulldown);
	set_input_pin(n64_VIDEO_D5, false, setAVPulldown);
	set_input_pin(n64_VIDEO_D6, false, setAVPulldown);
	set_input_pin(n64_VIDEO_DSYNC, false, setAVPulldown);
	set_input_pin(n64_VIDEO_CLK, false, false); // No pulldown on clock pins
	set_input_pin(n64_AUDIO_LRCLK, false, false);
	set_input_pin(n64_AUDIO_SDAT, false, setAVPulldown);
	set_input_pin(n64_AUDIO_BCLK, false, setAVPulldown);


	set_input_pin(n64_JOYBUS_CON1, false, false);

    // Video
    uint offset = pio_add_program(pio, &n64_program);
    n64_video_program_init(pio, sm_video, offset);
    pio_sm_set_enabled(pio, sm_video, true);

    // Audio
    n64_audio_program_init(pio, sm_audio, offset);
    pio_sm_set_enabled(pio, sm_audio, true);

    // Joybus RX
    uint offset_joybus = pio_add_program(pio_joybus, &joybus_program);
    joybus_rx_program_init(pio_joybus, sm_joybus, offset_joybus, n64_JOYBUS_CON1);
    pio_sm_set_enabled(pio_joybus, sm_joybus, true);

    // TODO: Move all stuff into this function
    joybus_rx_init(pio_joybus, sm_joybus);


    // Audio test data generators
#if 0
    for (int i = 0; i < AUDIO_BUFFER_SIZE; i++) {
        audio_buffer[i].channels[0] = rand();
        audio_buffer[i].channels[1] = rand();

        // audio_buffer_b[i].channels[0] = rand();
        // audio_buffer_b[i].channels[1] = rand();
    }
#elif 0
    // Generate sine
    // #define SAMPLE_RATE 96000
    #define SAMPLE_RATE 48000
    #define FREQUENCY1 375
    #define FREQUENCY2 (375 * 1.5)
    #define M_PI 3.1415926535

    for (int i = 0; i < AUDIO_BUFFER_SIZE; i++) {
        double time = (double)i / SAMPLE_RATE;
        int16_t sample1 = (int16_t)(16384.0 * sin(2.0 * M_PI * FREQUENCY1 * time));
        int16_t sample2 = (int16_t)(16384.0 * sin(2.0 * M_PI * FREQUENCY2 * time));

        audio_buffer[i].channels[0] = sample1;
        audio_buffer[i].channels[1] = sample2;
    }
#endif

    // DMA for Audio

    // Set up data + ctrl loop DMA jobs that read
    // from the audio PIO and write to a single 32bit word.
    // This is done, so we have a location in RAM where we always
    // have the _latest_ valid audio sample. This is needed because the FIFO filling speed.
    // A workaround is to push multiple times in the PIO, but that's ugly and breaks for low sample rates.
    uint dma_ch_audio_pio_data = dma_claim_unused_channel(true);
    uint dma_ch_audio_pio_ctrl = dma_claim_unused_channel(true);
    printf("dma_ch_audio_pio_data=%d\n", dma_ch_audio_pio_data);
    printf("dma_ch_audio_pio_ctrl=%d\n", dma_ch_audio_pio_ctrl);

    dma_channel_config c_audio_pio_data = dma_channel_get_default_config(dma_ch_audio_pio_data);
    channel_config_set_read_increment(&c_audio_pio_data, false);
    channel_config_set_dreq(&c_audio_pio_data, pio_get_dreq(pio, sm_audio, false));
    channel_config_set_chain_to(&c_audio_pio_data, dma_ch_audio_pio_ctrl);
    channel_config_set_irq_quiet(&c_audio_pio_data, true);

    const volatile void* ptr_audio_pio_rxf = &pio->rxf[sm_audio];
    dma_channel_configure(dma_ch_audio_pio_data, &c_audio_pio_data,
        &last_audio_sample,   // Write to last_audio_sample
        ptr_audio_pio_rxf,    // Read from RX FIFO
        1,                    // Sample one full buffer
        false                 // Do not start immediately
    );

    // Set up the control DMA to make dma_ch_audio_pio_data loop
    dma_channel_config c_audio_pio_ctrl = dma_channel_get_default_config(dma_ch_audio_pio_ctrl);
    channel_config_set_read_increment(&c_audio_pio_ctrl, false);
    channel_config_set_irq_quiet(&c_audio_pio_ctrl, true);
    dma_channel_configure(dma_ch_audio_pio_ctrl, &c_audio_pio_ctrl,
        &dma_hw->ch[dma_ch_audio_pio_data].al3_read_addr_trig, // Write to data DMA's read-address trigger register
        &ptr_audio_pio_rxf, // Read from ptr to RX FIFO
        1,                  // A single transfer is needed to restart data DMA
        true                // Start immediately
    );

    // Now there is a dma job running that reads the Audio PIO rx fifo, and puts it in last_audio_sample.
    // Set up data + ctrl loop DMA jobs that reads continuously with 96kHz from last_audio_sample
    // and write the result in a ringbuffer, audio_buffer.
    uint dma_ch_audio_buffer_data = dma_claim_unused_channel(true);
    uint dma_ch_audio_buffer_ctrl = dma_claim_unused_channel(true);
    printf("dma_ch_audio_buffer_data=%d\n", dma_ch_audio_buffer_data);
    printf("dma_ch_audio_buffer_ctrl=%d\n", dma_ch_audio_buffer_ctrl);

    // Chan A
    dma_channel_config c_audio_buffer_data = dma_channel_get_default_config(dma_ch_audio_buffer_data);
    channel_config_set_read_increment(&c_audio_buffer_data, false); // Read from the same place
    channel_config_set_write_increment(&c_audio_buffer_data, true); // Write the whole buffer
    channel_config_set_transfer_data_size(&c_audio_buffer_data, DMA_SIZE_32);
    channel_config_set_chain_to(&c_audio_buffer_data, dma_ch_audio_buffer_ctrl);
    channel_config_set_irq_quiet(&c_audio_buffer_data, true);

    // Configure the DMA timer that pulls the latest sample at a constant frequency
    dma_timer_claim(0);

    set_audio_sampling_parameters(g_config.audio_out_sample_rate);

    channel_config_set_dreq(&c_audio_buffer_data, DREQ_DMA_TIMER0);

    volatile void* ptr = &last_audio_sample;
    volatile void* ptr2 = &audio_buffer[0];

    dma_channel_configure(dma_ch_audio_buffer_data, &c_audio_buffer_data,
        ptr2,               // Destination pointer
        ptr,                // Source pointer
        AUDIO_BUFFER_SIZE,  // Sample the whole buffer
        false               // Do not start immediately
    );

    // The control DMA triggers the data DMA continuously via ping-pong chain
    dma_channel_config c_audio_buffer_ctrl = dma_channel_get_default_config(dma_ch_audio_buffer_ctrl);
    channel_config_set_read_increment(&c_audio_buffer_ctrl, false); // Always read one word
    channel_config_set_write_increment(&c_audio_buffer_ctrl, false); // Always write to data DMA's read-address trigger register
    channel_config_set_irq_quiet(&c_audio_buffer_ctrl, true);
    dma_channel_configure(dma_ch_audio_buffer_ctrl, &c_audio_buffer_ctrl,
        &dma_hw->ch[dma_ch_audio_buffer_data].al2_write_addr_trig,  // Destination pointer is data DMA's read-address trigger register
        &ptr2,               // Source pointer is the address of RX FIFO
        1,                   // A single transfer is needed to restart data DMA
        true                 // Start immediately
    );

    // Write to the beginning of the buffer, read from the middle
    set_read_offset(&dvi0.audio_ring, (AUDIO_BUFFER_SIZE) / 2);

    // Let the dvi code know which dma channel we use so it can query the write pointer
    dvi_audio_sample_dma_set_chan(&dvi0, dma_ch_audio_buffer_data, audio_buffer, 0, 0, AUDIO_BUFFER_SIZE);

#ifdef DIAGNOSTICS_JOYBUS

    uint32_t transfer = 0;
    uint32_t y = 0;

    gfx_puttextf(0, y++ * 8, 0xffff, 0x0000, "hello");
    gfx_puttextf(0, y++ * 8, 0xffff, 0x0000, "offset_joybus = %d", offset_joybus);

    while (true) {

        // The following code prints the raw PIO data
#if 0
        uint32_t value[8];
        for (int i = 0; i < 4; i++) {
            value[i] = pio_sm_get_blocking(pio_joybus, sm_joybus);
        }

        transfer++;

        gfx_puttextf(0, y++ * 8, 0xffff, 0x0000, "%02d: %08X %08X %08X %08X",
            transfer % 100, 
            value[0],
            value[1], value[2], value[3]);

        if (y > 24) {
            y = 0;
            sleep_ms(2000);
        }

#else
        // Use helper functions to decode the last controller state
        uint32_t value = joybus_rx_get_latest();

        y = 0;
        transfer++;

        gfx_puttextf(0, y++ * 8, 0xffff, 0x0000, "%02d: A=%d B=%d Z=%d Start=%d",
            transfer, 
            !!A_BUTTON(value), 
            !!B_BUTTON(value), 
            !!Z_BUTTON(value), 
            !!START_BUTTON(value));

        gfx_puttextf(0, y++ * 8, 0xffff, 0x0000, "%02d: DU=%d DD=%d DL=%d DR=%d",
            transfer, 
            !!DU_BUTTON(value), 
            !!DD_BUTTON(value), 
            !!DL_BUTTON(value), 
            !!DR_BUTTON(value));

        gfx_puttextf(0, y++ * 8, 0xffff, 0x0000, "%02d: Reset=%d",
            transfer, 
            !!RESET_BUTTON(value));

        gfx_puttextf(0, y++ * 8, 0xffff, 0x0000, "%02d: TL=%d TR=%d",
            transfer, 
            !!TL_BUTTON(value), 
            !!TR_BUTTON(value));

        gfx_puttextf(0, y++ * 8, 0xffff, 0x0000, "%02d: CU=%d CD=%d CL=%d CR=%d",
            transfer, 
            !!CU_BUTTON(value), 
            !!CD_BUTTON(value), 
            !!CL_BUTTON(value), 
            !!CR_BUTTON(value));

        gfx_puttextf(0, y++ * 8, 0xffff, 0x0000, "%02d: X=%04d Y=%04d",
            transfer, 
            X_STICK(value), 
            Y_STICK(value));
#endif

    }


#endif


    // Video

    int count = 0;
    int row = 0;
    int column = 0;

    #define CSYNCB_POS (0)
    #define HSYNCB_POS (1)
    #define CLAMPB_POS (2)
    #define VSYNCB_POS (3)

    #define CSYNCB_MASK (1 << CSYNCB_POS)
    #define HSYNCB_MASK (1 << HSYNCB_POS)
    #define CLAMPB_MASK (1 << CLAMPB_POS)
    #define VSYNCB_MASK (1 << VSYNCB_POS)

    #define ACTIVE_PIXEL_MASK (VSYNCB_MASK | HSYNCB_MASK | CLAMPB_MASK)

    /*
    0      8       10   15    1B  1F
                    v    v     v   v
                    RRRRRGGGGGGBBBBB
   xBBBBBBBxGGGGGGGxRRRRRRRXXXXVLHC
                 BBBBBBBxGGGGGGGxRRRRRRRxXXXXVLHC
                               BBBBBBBxGGGGGGGxRRRRRRRxXXXXVLHC
                 BBBBBBBxGGGGGGGxRRRRRRRxXXXXVLHC
    */

    uint32_t BGRS;
    uint32_t frame = 0;
    uint32_t crop_x = DEFAULT_CROP_X_PAL;
    uint32_t crop_y = DEFAULT_CROP_Y_PAL;
#ifdef DIAGNOSTICS
    const volatile uint32_t *pGetTime = &timer_hw->timerawl;
    uint32_t t0 = 0;
    uint32_t t1 = 0;
#endif

    while (1) {
        // printf("START\n");

        // Let the OSD code run
        osd_run();

        // 1. Find posedge VSYNC
        do {
            BGRS = pio_sm_get_blocking(pio, sm_video);
        } while (!(BGRS & VSYNCB_MASK));

        // printf("VSYNC\n");

        int active_row = 0;
        for (row = 0; ; row++) {

            int skip_row = (
                (row % 2 != 0) ||            // Skip every second line (TODO: Add blend option later)
                (row < crop_y) ||            // crop_y, number of rows to skip vertically from the top
                (active_row >= FRAME_HEIGHT) // Never attempt to write more rows than the g_framebuffer
            );

            // 2. Find posedge HSYNC
            do {
                BGRS = pio_sm_get_blocking(pio, sm_video);

                if ((BGRS & VSYNCB_MASK) == 0) {
                    // VSYNC found, time to quit
                    goto end_of_line;
                }

            } while ((BGRS & ACTIVE_PIXEL_MASK) != ACTIVE_PIXEL_MASK);

            if (skip_row) {
                // Skip rows based on logic above
                do {
                    BGRS = pio_sm_get_blocking(pio, sm_video);

                    if ((BGRS & VSYNCB_MASK) == 0) {
                        // VSYNC found, time to quit
                        goto end_of_line;
                    }
                } while ((BGRS & ACTIVE_PIXEL_MASK) == ACTIVE_PIXEL_MASK);

                continue;
            }

            // printf("HSYNC\n");
            count = active_row * FRAME_WIDTH;
            int count_max = count + FRAME_WIDTH;
            active_row++;

            column = 0;

            // 3.  Capture scanline

            // 3.1 Crop left black bar
            for (int left_ctr = 0; left_ctr < crop_x; left_ctr++) {
                BGRS = pio_sm_get_blocking(pio, sm_video);
            };

            // 3.2 Capture active pixels
            BGRS = pio_sm_get_blocking(pio, sm_video);

            // This code is duplucated for performance reasons - 555 and 565 respectively

            if (g_config.dvi_color_mode == DVI_RGB_555) {
                do {
                    // 3.3 Convert to RGB555
                    g_framebuf[count++] = (
                        ((BGRS <<  1) & 0xf800) |
                        ((BGRS >> 12) & 0x07e0) |
                        ((BGRS >> 26) & 0x001f)
                        // | 0x1f // Uncomment to tint everything with blue
                    );

                    // Never write more than the line width.
                    // Input might be weird and have too many active pixels - discard in those cases.
                    if (count >= count_max) {
                        do {
                            // Consume all active pixels
                            BGRS = pio_sm_get_blocking(pio, sm_video);
                        } while ((BGRS & ACTIVE_PIXEL_MASK) == ACTIVE_PIXEL_MASK);
                        break;
                    }

                    // 3.4 Skip every second pixel
                    BGRS = pio_sm_get_blocking(pio, sm_video);

                    // 3.5 Count number of pixels processed on this row
                    column += 2; // Fuse two increments into one instruction

                    // Fetch new pixel in the end, so the loop logic can react to it first
                    BGRS = pio_sm_get_blocking(pio, sm_video);
                } while (1);
            } else if (g_config.dvi_color_mode == DVI_RGB_565) {
                do {
                    // 3.3 Convert to RGB565
                    g_framebuf[count++] = (
                        ((BGRS <<  1) & 0xf800) |
                        ((BGRS >> 12) & 0x07c0) | // Mask so only 5 bits for green are used
                        ((BGRS >> 26) & 0x001f)
                        // | 0x1f // Uncomment to tint everything with blue
                    );

                    // Never write more than the line width.
                    // Input might be weird and have too many active pixels - discard in those cases.
                    if (count >= count_max) {
                        do {
                            // Consume all active pixels
                            BGRS = pio_sm_get_blocking(pio, sm_video);
                        } while ((BGRS & ACTIVE_PIXEL_MASK) == ACTIVE_PIXEL_MASK);
                        break;
                    }

                    // 3.4 Skip every second pixel
                    BGRS = pio_sm_get_blocking(pio, sm_video);

                    // 3.5 Count number of pixels processed on this row
                    column += 2; // Fuse two increments into one instruction

                    // Fetch new pixel in the end, so the loop logic can react to it first
                    BGRS = pio_sm_get_blocking(pio, sm_video);
                } while (1);
            } else {
                // Panic
            }
        }

end_of_line:
        // Show diagnostic information every 100 frames, for 1 second

#ifdef DIAGNOSTICS
        if (frame % (50) == 0) {
            uint32_t y = 0;
            t1 = *pGetTime;

            gfx_puttextf(0, ++y * 8, 0xffff, 0x0000, "Delta %d", (t1 - t0));
            gfx_puttextf(0, ++y * 8, 0xffff, 0x0000, "row %d", row);
            gfx_puttextf(0, ++y * 8, 0xffff, 0x0000, "column %d", column);
            gfx_puttextf(0, ++y * 8, 0xffff, 0x0000, "count %d", count);


            sleep_ms(2000);
            t0 = *pGetTime;
        }
#endif

        // Perform NTSC / PAL detection based on number of rows
        if (IN_TOLERANCE(row, ROWS_PAL, ROWS_TOLERANCE)) {
            crop_x = DEFAULT_CROP_X_PAL;
            crop_y = DEFAULT_CROP_Y_PAL;
        } else {
            // In case the mode can't be detected, default to NTSC as it crops fewer rows
            crop_x = DEFAULT_CROP_X_NTSC;
            crop_y = DEFAULT_CROP_Y_NTSC;
        }
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

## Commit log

2024-02-09 V1.0 Complete
    Uploaded V1.0 of board and schematic
    [BOM_N64 SpyDVI_2024-02-09.csv, PickAndPlace_N64 SpyDVI_2024-02-09.csv]
2024-02-09 Restructure / Add Step File
    Restructure the project a bit, add the STEP file for assembled board, add images.
    [BOM_N64 SpyDVI_2024-02-09.csv, PickAndPlace_N64 SpyDVI_2024-02-09.csv]
2024-02-09 Fix folder naming mistake
    [BOM_N64 SpyDVI_2024-02-09.csv, PickAndPlace_N64 SpyDVI_2024-02-09.csv]
2024-02-16 Converted to 4-layer board
2024-02-16 Upload V2.0 Files
    [BOM_N64 SpyDVI_2024-02-16.csv, PickAndPlace_N64 SpyDVI_2024-02-16.csv]
2024-02-24 Reroute for V2.1
    - Rewired entire board to resolve potential short on motherboard shield and improve routing
    - Exchanged 3 headers for a single 20-pin 1.27mm header.
    - Header pinout changed to make install cleaner
    - Exchanged some 'extended' parts for 'basic' parts to reduce manufacture cost
    - Removed physical reset button in favor of 2 pads.
    - Included a keep-out region in board outline DXF (Motherboard Shield)
    - Added PNG of schematic
    [BOM_N64 SpyDVI_2024-02-23.csv, PickAndPlace_N64 SpyDVI_2024-02-24.csv, SpyDVIBoardOutline.dxf]
2024-02-25 V2.2
    - Updated via sizes to avoid manufacturing charges
    - Updated Readme
    - Updated images
    - Fixed BOM missing debug header
    - Fixed BOM including RESET pads
    [BOM_N64 SpyDVI_2024-02-24.csv, PickAndPlace_N64 SpyDVI_2024-02-24.csv]
2024-02-25 Added Wiring Diagram
2024-03-08 Updated UART Greeting;
2024-08-21 V2_4
    Removed N64 Header
    Added QSB
    [BOM_N64 SpyDVI QSB_1-PCB_PCB_N64 SpyDVI QSB_2024-08-21.xlsx, BOM_N64 SpyDVI_2024-02-09.csv, BOM_N64 SpyDVI_2024-02-16.csv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]
2024-08-22 Ribbon V1.1 and V1.0C
    Added Compatability Ribbon and V1.1 of the main ribbon fixes a few DRC errors and removes solder mask on connector pads.
    [BOM_N64 SpyDVI QSB Compat_PCB_QSBC_2024-08-22.xlsx, BOM_N64 SpyDVI QSB_1-PCB_PCB_N64 SpyDVI QSB_2024-08-22.xlsx, PickAndPlace_1-PCB_PCB_N64 SpyDVI QSB_2024-08-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]
2024-08-22 Re-export Ribbon V1.1
    Moving Decals, not worth whole revision
    [PickAndPlace_1-PCB_PCB_N64 SpyDVI QSB_2024-08-22.xlsx]
2024-08-31 No Cut Kit Files
    [N64 Bracket.stl, N64Adv2_MultiOut_NoCut.stl]
